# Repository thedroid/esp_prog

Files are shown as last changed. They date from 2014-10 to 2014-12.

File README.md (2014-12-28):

# ESP8266 Programmer
A extension for the [`esptool`](https://github.com/themadinventor/esptool) originally written by Fredrik Ahlberg. The tool now enters the boot-loader mode w/o the need of a user interaction.

# Folders

## esptool
Modified version of the original tool.

## schematic
Required hardware

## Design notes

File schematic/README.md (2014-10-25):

# Hardware

In order to enter the bootloader GPIO0 needs to be low at system start. Before the regular programming/flashing is taking place, the modified `esptool` ensures that by using the spare RTS and DTR lines of the serial port. 
A reset is carried out by the RTS line while GPIO0 is held low via the DTR line.

Note that, we silently assume that GPIO2 and GPIO15 are pulled high during system start.

# Wiring

## Diagram

FTDI |Connection| ESP8266 | Note
:-----:|:----------:|:---------:|------
TX   |   ----   | RX      |
RX   |   ----   | TX      | 
RTS  | 220Ohm | Reset   | see considerations
DTR  | 220Ohm | GPIO0   | see considerations
Vio  | 56Ohm | Vdd     | Optional. Vio can alternativly be connected to 3.3Vout of the FTDI. Just ensure 3.3V levels.
GND  |   ----   | Vss     |

## Considerations
Open-drain output for DTR/RTS would be ideal for a true In System Programmer (ISP). In dormant state they would leave the actual circuit unaffected. However, the lines are active low. Meaning that during inactivity the lines are high. A double inverting MOSFET stage would be required to accomplish the desired behavior. As the same issues holds for the TX line I currently decided to go with the simple and cheap solution: resistors. The more advanced solution would be a driver IC which switches RTS, DTR, and TX into a Tri-Z state. The driver could be controlled by the DTR line.

## Pinout

The ESP-03/4 has the most GPIO pins. Thus, it is most likely that the majority of the people actively developing code for this chip will use this model and its specific pin configuration. 
The following pinout of the ISP is optimized for the usage of the ESP-03/4 board on top of a single sided PCB. A 6 pin (3x2) SMD header can easily be routed w/o intersections. Making it perfect for low-cost home-echted PCBs.
 
Pin header on the PCB (top view):

Description |   |   | Description
------------:|:---:|:---:|:------------
Vss         | 1 | 2 | Tx
Rx          | 3 | 4 | /Reset
Vdd         | 5 | 6 | GPIO0

Note that, for the ISP cable the RX/TX lines need to be twisted.

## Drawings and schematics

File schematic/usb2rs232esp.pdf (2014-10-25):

A

A

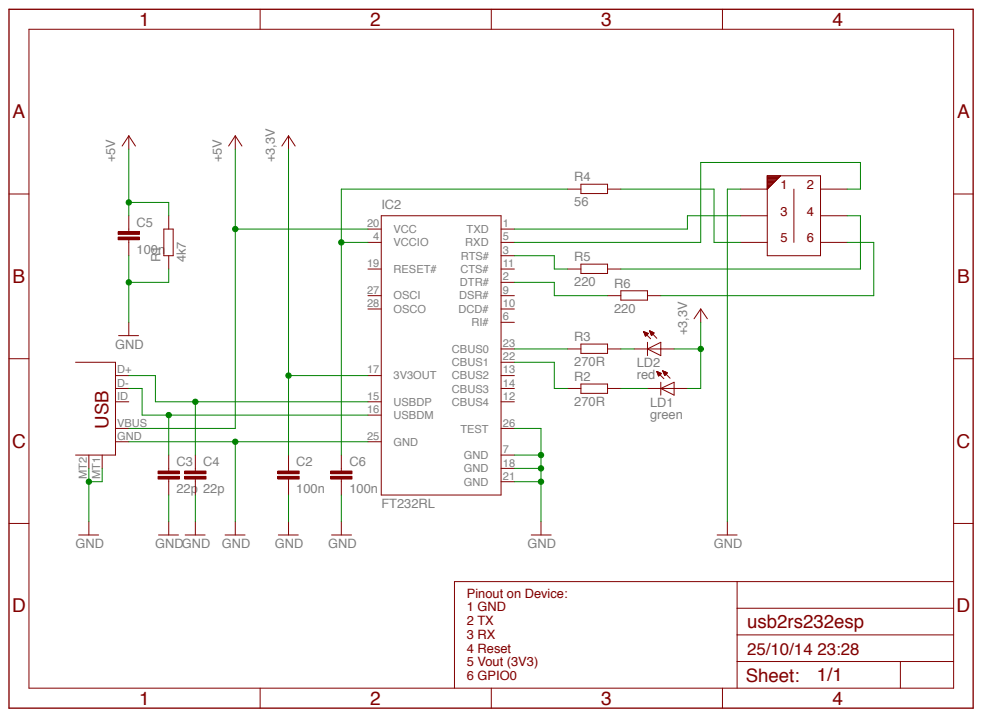
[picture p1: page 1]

Pinout on Device: 1 GND 2 TX 3 RX 4 Reset 5 Vout (3V3) 6 GPIO0

Sheet: 1/1

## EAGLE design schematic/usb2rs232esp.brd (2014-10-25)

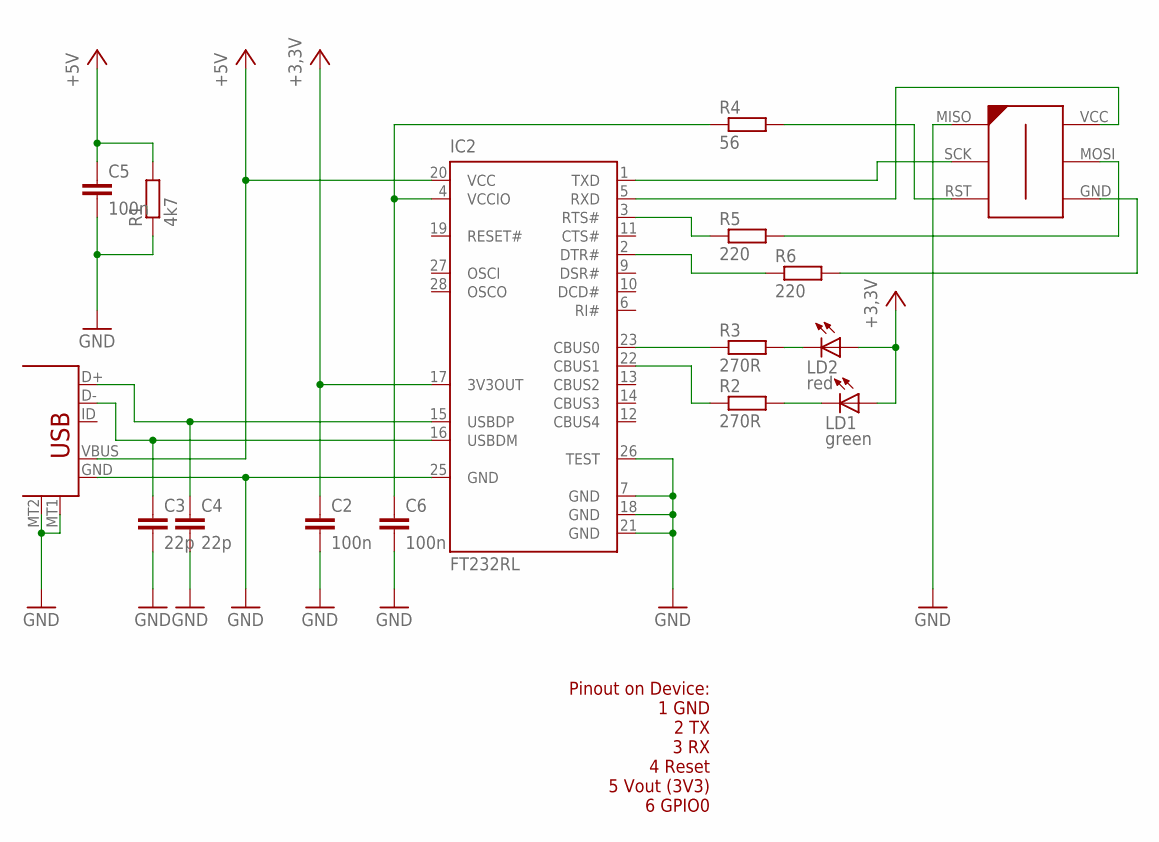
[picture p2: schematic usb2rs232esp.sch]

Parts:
C2, C5, C6: 100n; C0603
C3, C4: 22p; C0603
IC2: FT232RL; SSOP28
LD1: green; CHIP-LED0603
LD2: red; CHIP-LED0603
R1: 4k7; R0603
R2, R3: 270R; R0603
R4: 56; R0603
R5, R6: 220; R0603
U$3: AVR-ISP-6-EDGE; 6PAD_ISP
U$40: USB-B; USB-MICROB

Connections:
+3,3V: C2.1, IC2.17 (3V3OUT), LD1.A, LD2.A
+5V: C5.1, IC2.20 (VCC), R1.2, U$40.VBUS
GND: C2.2, C3.2, C4.2, C5.2, C6.2, IC2.7 (GND), IC2.18 (GND), IC2.21 (GND), IC2.25 (GND), IC2.26 (TEST), R1.1, U$3.MISO, U$40.GND, U$40.MT1, U$40.MT2
unnamed: IC2.23 (CBUS0), R3.1
unnamed: IC2.22 (CBUS1), R2.1
unnamed: C4.1, IC2.15 (USBDP), U$40.D+
unnamed: C3.1, IC2.16 (USBDM), U$40.D-
unnamed: C6.1, IC2.4 (VCCIO), R4.1
unnamed: LD1.C, R2.2
unnamed: LD2.C, R3.2
unnamed: R4.2, U$3.RST
unnamed: R5.2, U$3.MOSI
unnamed: R6.2, U$3.GND
unnamed: IC2.5 (RXD), U$3.VCC
unnamed: IC2.1 (TXD), U$3.SCK
unnamed: IC2.3 (RTS#), R5.1
unnamed: IC2.2 (DTR#), R6.1

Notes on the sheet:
Pinout on Device: 1 GND 2 TX 3 RX 4 Reset 5 Vout (3V3) 6 GPIO0

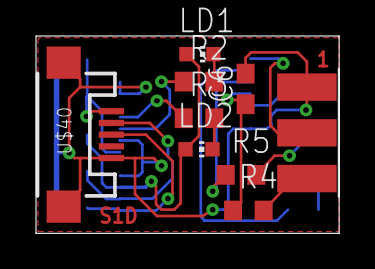
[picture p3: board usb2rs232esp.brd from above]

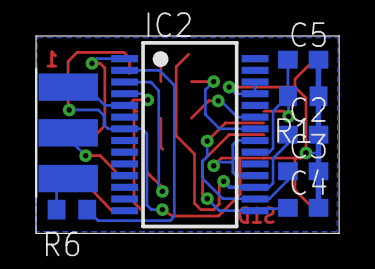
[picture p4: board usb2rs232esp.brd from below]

Board: 2 copper layers, 16.8 x 11.0 mm, 16 parts (7 on the bottom side), 17 nets.

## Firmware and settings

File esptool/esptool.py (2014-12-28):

#!/usr/bin/env python2.7
#
# ESP8266 ROM Bootloader Utility
# https://github.com/themadinventor/esptool
#
# Copyright (C) 2014 Fredrik Ahlberg
# Modified by Juergen Eckert (2014)
#
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
import sys
import struct
import serial
import math
import time
import argparse
import os
import subprocess

class ESPROM:

    # These are the currently known commands supported by the ROM
    ESP_FLASH_BEGIN = 0x02
    ESP_FLASH_DATA  = 0x03
    ESP_FLASH_END   = 0x04
    ESP_MEM_BEGIN   = 0x05
    ESP_MEM_END     = 0x06
    ESP_MEM_DATA    = 0x07
    ESP_SYNC        = 0x08
    ESP_WRITE_REG   = 0x09
    ESP_READ_REG    = 0x0a

    # Maximum block sized for RAM and Flash writes, respectively.
    ESP_RAM_BLOCK   = 0x1800
    ESP_FLASH_BLOCK = 0x100

    # Default baudrate. The ROM auto-bauds, so we can use more or less whatever we want.
    ESP_ROM_BAUD    = 115200

    # First byte of the application image
    ESP_IMAGE_MAGIC = 0xe9

    # Initial state for the checksum routine
    ESP_CHECKSUM_MAGIC = 0xef

    # OTP ROM addresses
    ESP_OTP_MAC0    = 0x3ff00050
    ESP_OTP_MAC1    = 0x3ff00054

    def __init__(self, port = 0, baud = ESP_ROM_BAUD):
        self._port = serial.Serial(port, baud)

    """ Read bytes from the serial port while performing SLIP unescaping """
    def read(self, length = 1):
        b = ''
        while len(b) < length:
            c = self._port.read(1)
            if c == '\xdb':
                c = self._port.read(1)
                if c == '\xdc':
                    b = b + '\xc0'
                elif c == '\xdd':
                    b = b + '\xdb'
                else:
                    raise Exception('Invalid SLIP escape')
            else:
                b = b + c
        return b

    """ Write bytes to the serial port while performing SLIP escaping """
    def write(self, packet):
        buf = '\xc0'
        for b in packet:
            if b == '\xc0':
                buf += '\xdb\xdc'
            elif b == '\xdb':
                buf += '\xdb\xdd'
            else:
                buf += b
        buf += '\xc0'
        self._port.write(buf)

    """ Calculate checksum of a blob, as it is defined by the ROM """
    @staticmethod
    def checksum(data, state = ESP_CHECKSUM_MAGIC):
        for b in data:
            state ^= ord(b)
        return state

    """ Send a request and read the response """
    def command(self, op = None, data = None, chk = 0):
        if op:
            # Construct and send request
            pkt = struct.pack('<BBHI', 0x00, op, len(data), chk) + data
            self.write(pkt)

        # Read header of response and parse
        if self._port.read(1) != '\xc0':
            raise Exception('Invalid head of packet')
        hdr = self.read(8)
        (resp, op_ret, len_ret, val) = struct.unpack('<BBHI', hdr)
        if resp != 0x01 or (op and op_ret != op):
            raise Exception('Invalid response')

        # The variable-length body
        body = self.read(len_ret)

        # Terminating byte
        if self._port.read(1) != chr(0xc0):
            raise Exception('Invalid end of packet')

        return val, body

    """ Perform a connection test """
    def sync(self):
        self.command(ESPROM.ESP_SYNC, '\x07\x07\x12\x20'+32*'\x55')
        for i in xrange(7):
            self.command()

    """ Try connecting repeatedly until successful, or giving up """
    def connect(self):
	print 'Entering bootloader...'
	self._port.setRTS(True)			#RTS
	self._port.setDTR(True)			#GPIO0
	time.sleep(0.25)
	self._port.setRTS(False)
	self._port.setDTR(True)
	time.sleep(0.25)
        self._port.setRTS(False)
	self._port.setDTR(False)

        print 'Connecting...'

        # RTS = CH_PD (i.e reset)
        # DTR = GPIO0
        self._port.setRTS(True)
        self._port.setDTR(True)
        self._port.setRTS(False)
        time.sleep(0.1)
        self._port.setDTR(False)

        self._port.timeout = 0.5
        for i in xrange(10):
            try:
                self._port.flushInput()
                self._port.flushOutput()
                self.sync()
                self._port.timeout = 5
                return
            except:
                time.sleep(0.1)
        raise Exception('Failed to connect')

    """ Read memory address in target """
    def read_reg(self, addr):
        res = self.command(ESPROM.ESP_READ_REG, struct.pack('<I', addr))
        if res[1] != "\0\0":
            raise Exception('Failed to read target memory')
        return res[0]

    """ Write to memory address in target """
    def write_reg(self, addr, value, mask, delay_us = 0):
        if self.command(ESPROM.ESP_WRITE_REG,
                struct.pack('<IIII', addr, value, mask, delay_us))[1] != "\0\0":
            raise Exception('Failed to write target memory')

    """ Start downloading an application image to RAM """
    def mem_begin(self, size, blocks, blocksize, offset):
        if self.command(ESPROM.ESP_MEM_BEGIN,
                struct.pack('<IIII', size, blocks, blocksize, offset))[1] != "\0\0":
            raise Exception('Failed to enter RAM download mode')

    """ Send a block of an image to RAM """
    def mem_block(self, data, seq):
        if self.command(ESPROM.ESP_MEM_DATA,
                struct.pack('<IIII', len(data), seq, 0, 0)+data, ESPROM.checksum(data))[1] != "\0\0":
            raise Exception('Failed to write to target RAM')

    """ Leave download mode and run the application """
    def mem_finish(self, entrypoint = 0):
        if self.command(ESPROM.ESP_MEM_END,
                struct.pack('<II', int(entrypoint == 0), entrypoint))[1] != "\0\0":
            raise Exception('Failed to leave RAM download mode')

    """ Start downloading to Flash (performs an erase) """
    def flash_begin(self, size, offset):
        old_tmo = self._port.timeout
        num_blocks = (size + ESPROM.ESP_FLASH_BLOCK - 1) / ESPROM.ESP_FLASH_BLOCK
        self._port.timeout = 10
        if self.command(ESPROM.ESP_FLASH_BEGIN,
                struct.pack('<IIII', size, num_blocks, ESPROM.ESP_FLASH_BLOCK, offset))[1] != "\0\0":
            raise Exception('Failed to enter Flash download mode')
        self._port.timeout = old_tmo

    """ Write block to flash """
    def flash_block(self, data, seq):
        if self.command(ESPROM.ESP_FLASH_DATA,
                struct.pack('<IIII', len(data), seq, 0, 0)+data, ESPROM.checksum(data))[1] != "\0\0":
            raise Exception('Failed to write to target Flash')

    """ Leave flash mode and run/reboot """
    def flash_finish(self, reboot = False):
        pkt = struct.pack('<I', int(not reboot))
        if self.command(ESPROM.ESP_FLASH_END, pkt)[1] != "\0\0":
            raise Exception('Failed to leave Flash mode')

    """ Run application code in flash """
    def run(self, reboot = False):
        # Fake flash begin immediately followed by flash end
        self.flash_begin(0, 0)
        self.flash_finish(reboot)


class ESPFirmwareImage:
    
    def __init__(self, filename = None):
        self.segments = []
        self.entrypoint = 0

        if filename is not None:
            f = file(filename, 'rb')
            (magic, segments, _, _, self.entrypoint) = struct.unpack('<BBBBI', f.read(8))
            
            # some sanity check
            if magic != ESPROM.ESP_IMAGE_MAGIC or segments > 16:
                raise Exception('Invalid firmware image')
        
            for i in xrange(segments):
                (offset, size) = struct.unpack('<II', f.read(8))
                if offset > 0x40200000 or offset < 0x3ffe0000 or size > 65536:
                    raise Exception('Suspicious segment %x,%d' % (offset, size))
                self.segments.append((offset, size, f.read(size)))

            # Skip the padding. The checksum is stored in the last byte so that the
            # file is a multiple of 16 bytes.
            align = 15-(f.tell() % 16)
            f.seek(align, 1)

            self.checksum = ord(f.read(1))

    def add_segment(self, addr, data):
        # Data should be aligned on word boundary
        l = len(data)
        if l % 4:
            data += b"\x00" * (4 - l % 4)
        self.segments.append((addr, len(data), data))

    def save(self, filename):
        f = file(filename, 'wb')
        f.write(struct.pack('<BBBBI', ESPROM.ESP_IMAGE_MAGIC, len(self.segments), 0, 0, self.entrypoint))

        checksum = ESPROM.ESP_CHECKSUM_MAGIC
        for (offset, size, data) in self.segments:
            f.write(struct.pack('<II', offset, size))
            f.write(data)
            checksum = ESPROM.checksum(data, checksum)

        align = 15-(f.tell() % 16)
        f.seek(align, 1)
        f.write(struct.pack('B', checksum))


class ELFFile:

    def __init__(self, name):
        self.name = name
        self.symbols = None

    def _fetch_symbols(self):
        if self.symbols is not None:
            return
        self.symbols = {}
        try:
            proc = subprocess.Popen(["xtensa-lx106-elf-nm", self.name], stdout=subprocess.PIPE)
        except OSError:
            print "Error calling xtensa-lx106-elf-nm, do you have Xtensa toolchain in PATH?"
            sys.exit(1)
        for l in proc.stdout:
            fields = l.strip().split()
            self.symbols[fields[2]] = int(fields[0], 16)

    def get_symbol_addr(self, sym):
        self._fetch_symbols()
        return self.symbols[sym]

    def load_section(self, section):
        subprocess.check_call(["xtensa-lx106-elf-objcopy", "--only-section", section, "-Obinary", self.name, ".tmp.section"])
        f = open(".tmp.section", "rb")
        data = f.read()
        f.close()
        os.remove(".tmp.section")
        return data


def arg_auto_int(x):
    return int(x, 0)

if __name__ == '__main__':
    parser = argparse.ArgumentParser(description = 'ESP8266 ROM Bootloader Utility', prog = 'esptool')

    parser.add_argument(
            '--port', '-p',
            help = 'Serial port device',
            default = '/dev/ttyUSB0')

    parser.add_argument(
            '--baud', '-b',
            help = 'Serial port baud rate',
            type = arg_auto_int,
            default = ESPROM.ESP_ROM_BAUD)

    subparsers = parser.add_subparsers(
            dest = 'operation',
            help = 'Run esptool {command} -h for additional help')

    parser_load_ram = subparsers.add_parser(
            'load_ram',
            help = 'Download an image to RAM and execute')
    parser_load_ram.add_argument('filename', help = 'Firmware image')

    parser_dump_mem = subparsers.add_parser(
            'dump_mem',
            help = 'Dump arbitrary memory to disk')
    parser_dump_mem.add_argument('address', help = 'Base address', type = arg_auto_int)
    parser_dump_mem.add_argument('size', help = 'Size of region to dump', type = arg_auto_int)
    parser_dump_mem.add_argument('filename', help = 'Name of binary dump')

    parser_read_mem = subparsers.add_parser(
            'read_mem',
            help = 'Read arbitrary memory location')
    parser_read_mem.add_argument('address', help = 'Address to read', type = arg_auto_int)

    parser_write_mem = subparsers.add_parser(
            'write_mem',
            help = 'Read-modify-write to arbitrary memory location')
    parser_write_mem.add_argument('address', help = 'Address to write', type = arg_auto_int)
    parser_write_mem.add_argument('value', help = 'Value', type = arg_auto_int)
    parser_write_mem.add_argument('mask', help = 'Mask of bits to write', type = arg_auto_int)

    parser_write_flash = subparsers.add_parser(
            'write_flash',
            help = 'Write a binary blob to flash')
    parser_write_flash.add_argument('addr_filename', nargs = '+', help = 'Address and binary file to write there, separated by space')

    parser_run = subparsers.add_parser(
            'run',
            help = 'Run application code in flash')

    parser_image_info = subparsers.add_parser(
            'image_info',
            help = 'Dump headers from an application image')
    parser_image_info.add_argument('filename', help = 'Image file to parse')

    parser_make_image = subparsers.add_parser(
            'make_image',
            help = 'Create an application image from binary files')
    parser_make_image.add_argument('output', help = 'Output image file')
    parser_make_image.add_argument('--segfile', '-f', action = 'append', help = 'Segment input file') 
    parser_make_image.add_argument('--segaddr', '-a', action = 'append', help = 'Segment base address', type = arg_auto_int) 
    parser_make_image.add_argument('--entrypoint', '-e', help = 'Address of entry point', type = arg_auto_int, default = 0)

    parser_elf2image = subparsers.add_parser(
            'elf2image',
            help = 'Create an application image from ELF file')
    parser_elf2image.add_argument('input', help = 'Input ELF file')
    parser_elf2image.add_argument('--output', '-o', help = 'Output filename prefix', type = str)

    parser_read_mac = subparsers.add_parser(
            'read_mac',
            help = 'Read MAC address from OTP ROM')

    args = parser.parse_args()

    # Create the ESPROM connection object, if needed
    esp = None
    if args.operation not in ('image_info','make_image','elf2image'):
        esp = ESPROM(args.port, args.baud)
        esp.connect()

    # Do the actual work. Should probably be split into separate functions.
    if args.operation == 'load_ram':
        image = ESPFirmwareImage(args.filename)

        print 'RAM boot...'
        for (offset, size, data) in image.segments:
            print 'Downloading %d bytes at %08x...' % (size, offset),
            sys.stdout.flush()
            esp.mem_begin(size, math.ceil(size / float(esp.ESP_RAM_BLOCK)), esp.ESP_RAM_BLOCK, offset)

            seq = 0
            while len(data) > 0:
                esp.mem_block(data[0:esp.ESP_RAM_BLOCK], seq)
                data = data[esp.ESP_RAM_BLOCK:]
                seq += 1
            print 'done!'

        print 'All segments done, executing at %08x' % image.entrypoint
        esp.mem_finish(image.entrypoint)

    elif args.operation == 'read_mem':
        print '0x%08x = 0x%08x' % (args.address, esp.read_reg(args.address))

    elif args.operation == 'write_mem':
        esp.write_reg(args.address, args.value, args.mask, 0)
        print 'Wrote %08x, mask %08x to %08x' % (args.value, args.mask, args.address)

    elif args.operation == 'dump_mem':
        f = file(args.filename, 'wb')
        for i in xrange(args.size/4):
            d = esp.read_reg(args.address+(i*4))
            f.write(struct.pack('<I', d))
            if f.tell() % 1024 == 0:
                print '\r%d bytes read... (%d %%)' % (f.tell(), f.tell()*100/args.size),
                sys.stdout.flush()
        print 'Done!'

    elif args.operation == 'write_flash':
        assert len(args.addr_filename) % 2 == 0
        while args.addr_filename:
            address = int(args.addr_filename[0], 0)
            filename = args.addr_filename[1]
            args.addr_filename = args.addr_filename[2:]
            image = file(filename, 'rb').read()
            print 'Erasing flash...'
            blocks = math.ceil(len(image)/float(esp.ESP_FLASH_BLOCK))
            esp.flash_begin(blocks*esp.ESP_FLASH_BLOCK, address)
            seq = 0
            while len(image) > 0:
                print '\rWriting at 0x%08x... (%d %%)' % (address + seq*esp.ESP_FLASH_BLOCK, 100*(seq+1)/blocks),
                sys.stdout.flush()
                block = image[0:esp.ESP_FLASH_BLOCK]
                block = block + '\xe0' * (esp.ESP_FLASH_BLOCK-len(block))
                esp.flash_block(block, seq)
                image = image[esp.ESP_FLASH_BLOCK:]
                seq += 1
            print
        print '\nLeaving...'
        esp.flash_finish(False)

    elif args.operation == 'run':
        esp.run()

    elif args.operation == 'image_info':
        image = ESPFirmwareImage(args.filename)
        print ('Entry point: %08x' % image.entrypoint) if image.entrypoint != 0 else 'Entry point not set'
        print '%d segments' % len(image.segments)
        print
        checksum = ESPROM.ESP_CHECKSUM_MAGIC
        for (idx, (offset, size, data)) in enumerate(image.segments):
            print 'Segment %d: %5d bytes at %08x' % (idx+1, size, offset)
            checksum = ESPROM.checksum(data, checksum)
        print
        print 'Checksum: %02x (%s)' % (image.checksum, 'valid' if image.checksum == checksum else 'invalid!')

    elif args.operation == 'make_image':
        image = ESPFirmwareImage()
        if len(args.segfile) == 0:
            raise Exception('No segments specified')
        if len(args.segfile) != len(args.segaddr):
            raise Exception('Number of specified files does not match number of specified addresses')
        for (seg, addr) in zip(args.segfile, args.segaddr):
            data = file(seg, 'rb').read()
            image.add_segment(addr, data)
        image.entrypoint = args.entrypoint
        image.save(args.output)

    elif args.operation == 'elf2image':
        if args.output is None:
            args.output = args.input + '-'
        e = ELFFile(args.input)
        image = ESPFirmwareImage()
        image.entrypoint = e.get_symbol_addr("call_user_start")
        for section, start in ((".text", "_text_start"), (".data", "_data_start"), (".rodata", "_rodata_start")):
            data = e.load_section(section)
            image.add_segment(e.get_symbol_addr(start), data)
        image.save(args.output + "0x00000.bin")
        data = e.load_section(".irom0.text")
        off = e.get_symbol_addr("_irom0_text_start") - 0x40200000
        assert off >= 0
        f = open(args.output + "0x%05x.bin" % off, "wb")
        f.write(data)
        f.close()

    elif args.operation == 'read_mac':
        mac0 = esp.read_reg(esp.ESP_OTP_MAC0)
        mac1 = esp.read_reg(esp.ESP_OTP_MAC1)
        print 'MAC: 18:fe:34:%02x:%02x:%02x' % ((mac1 >> 8) & 0xff, mac1 & 0xff, (mac0 >> 24) & 0xff)

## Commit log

2014-10-25 Initial commit
    -Moved esptool into dedicated directory
    -Intoduced schematics
    [usb2rs232esp.brd, usb2rs232esp.sch]
2014-10-25 improved lables
    [usb2rs232esp.sch]

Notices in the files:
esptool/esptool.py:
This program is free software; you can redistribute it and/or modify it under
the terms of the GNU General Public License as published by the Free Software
